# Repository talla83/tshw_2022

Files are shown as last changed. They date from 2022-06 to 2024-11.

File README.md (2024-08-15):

# tshw_2022
# PCB for Tom Simple CNC Handwheel (Mesa SmartSerial)

# Neue Dokumentation 2024 !!!
# https://www.patreon.com/posts/tom-simple-2024-110112296

- 16 Inputs / 16 Outputs / 2 Analog Inputs / 1 Encoder Input
- Interface: RS422
- Protocol: Mesa SmartSerial

The Frame: (3D Printing)
https://www.thingiverse.com/thing:3684937

This is an image

Achtung:
Die Pulldownwiderstände R7,R8,R9,R10,R11,R12,R13,R14,R15,R16,R17,R18,R19,R20,R21,R22 
können einen Wert zwischen 300 ohm bis 10 kOhm haben.

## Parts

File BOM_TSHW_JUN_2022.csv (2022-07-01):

ID | Name | Designator | Footprint | Quantity | Manufacturer Part | Manufacturer | Supplier | Supplier Part | Price
1 | 1K | R2,R1 | R1206 | 2 |  |  | LCSC | C510121 | 0.043
2 | 1K | R7,R8,R9,R10,R11,R12,R13,R14,R15,R16,R17,R18,R19,R20,R21,R22 | R1206 | 16 | 1K - 10K |  | LCSC | C510121 | 0.004
3 | 4,7K | R23,R25 | R1206 | 2 |  |  | LCSC | C510121 | 0.043
4 | 100nF | C10,C11,C1,C2,C3,C4,C5,C6,C7,C12,C13,C14,C15 | C1206 | 13 | FN21X104K500PXG | Prosperity Dielectrics | LCSC | C235732 | 0.007
5 | 74HC14D,653 | U2 | SOIC-14_L8.7-W3.9-P1.27-LS6.0-BL | 1 | 74HC14D,653 | Nexperia | LCSC | C5605 | 0.224
6 | 4.7K | R3,R4,R5,R6 | R1206 | 4 | RS-05K472JT | FH | LCSC | C115310 | 0.001
7 | HDR-M-2.54_1x4 | J9 | HDR-M-2.54_1X4 | 1 |  |  | LCSC | C124378 | 0.045
8 | HDR-M-2.54_1x2 | J8,J7 | HDR-M-2.54_1X2 | 2 |  |  | LCSC | C124375 | 0.027
9 | HDR-M-2.54_1x5 | ICSP1 | HDR-M-2.54_1X5 | 1 |  |  | LCSC | C358687 | 0.026
10 | HDR-M-2.54_1x6 | J1,J2 | HDR-M-2.54_1X6 | 2 |  |  | LCSC | C190819 | 0.037
11 | AMS1117-3.3 | L1 | SOT-223-3_L6.5-W3.4-P2.30-LS7.0-BR | 1 | AMS1117-3.3 | AMS | LCSC | C6186 | 0.14
12 | 10MHz | OSC1 | OSC-SMD_CSTCC_G_A | 1 | CSTCC10M0G53-R0 | MuRata | LCSC | C63590 | 0.262
13 | 15-21/G6C-AN1P2/2T | E1 | LED0805-RD_RED | 1 | 17-21UGC/TR8 | Everlight Elec | LCSC | C264418 | 0.053
14 | MAX3491ESD+T | U1 | SOP-14_L8.6-W3.9-P1.27-LS6.0-BL | 1 | MAX3491ESD+T | MAXIM | LCSC | C61053 | 2.846
15 | 74HC597D,652 | U3,U4 | SO-16_L9.9-W3.9-P1.27-LS6.0-BL | 2 | 74HC597D,652 | Nexperia | LCSC | C547129 | 1.121
16 | 74HC595D,112 | U5,U6 | SO-16_L9.9-W3.9-P1.27-LS6.0-BL | 2 | 74HC595D,112 | Nexperia | LCSC | C547124 | 0.303
17 | DSPIC33EP32MC204-I/PT | IC1 | TQFP-44_L10.0-W10.0-P0.80-BL | 1 | DSPIC33EP32MC204-I/PT | MICROCHIP | LCSC | C141373 | 6.813
18 | 47uF | C8 | CAP-SMD_L3.5-W2.8-R-RD | 1 | 10TPE47MAZB | PANASONIC | LCSC | C147768 | 0.638
19 | 22uF | C9 | CAP-SMD_L7.3-W4.3-FD | 1 | 25TQC22MYFD | PANASONIC | LCSC | C129172 | 0.666
20 | HDR-M-2.54_1x8 | J3,J4,J5,J6 | HDR-M-2.54_1X8 | 4 |  |  | LCSC | C190820 | 0.042

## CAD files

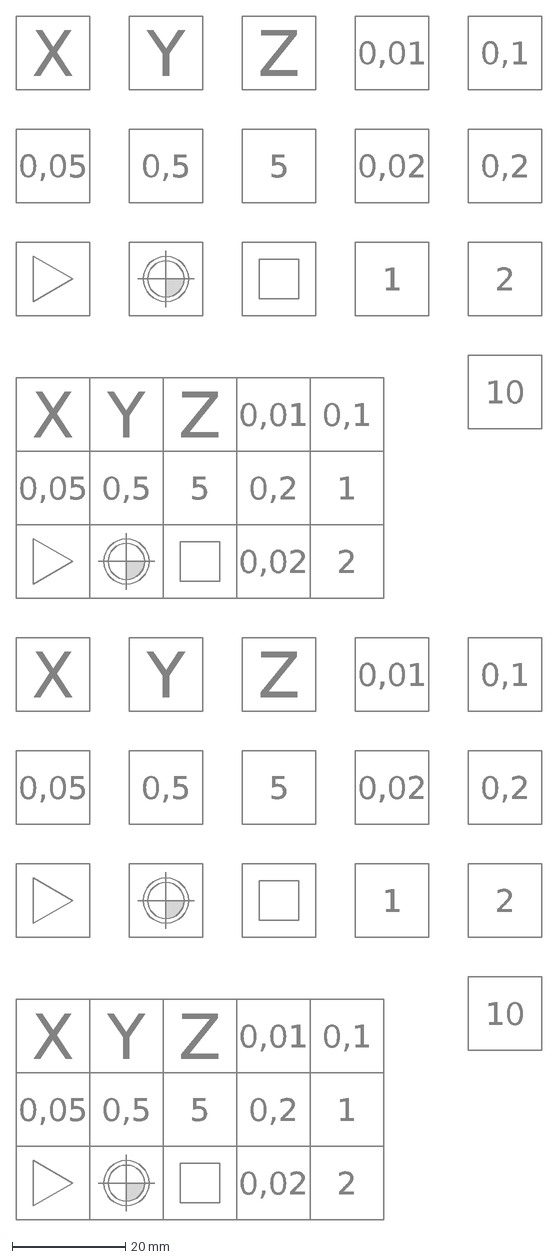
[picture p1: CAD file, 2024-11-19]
Handrad Druckdatei.dxf
X
Y
Z
0,05
0,5
5
0,01
0,1
1
0,02
0,2
2
10

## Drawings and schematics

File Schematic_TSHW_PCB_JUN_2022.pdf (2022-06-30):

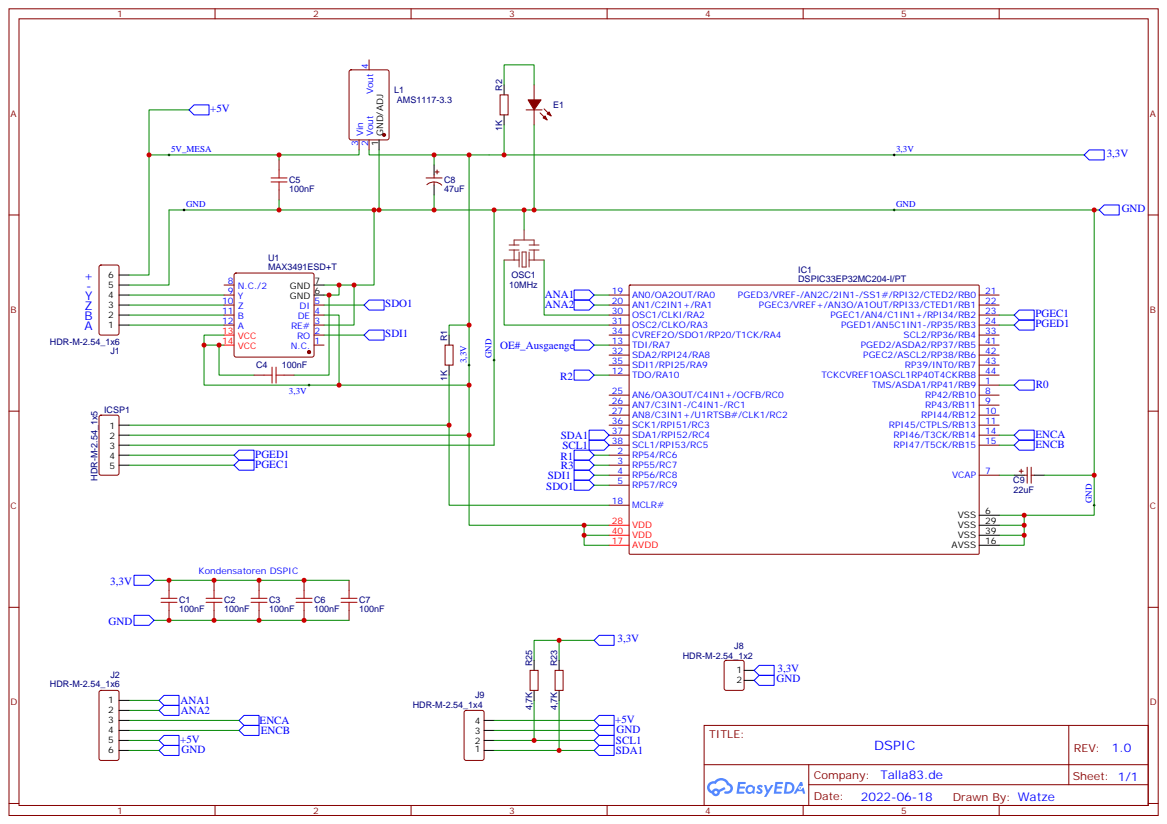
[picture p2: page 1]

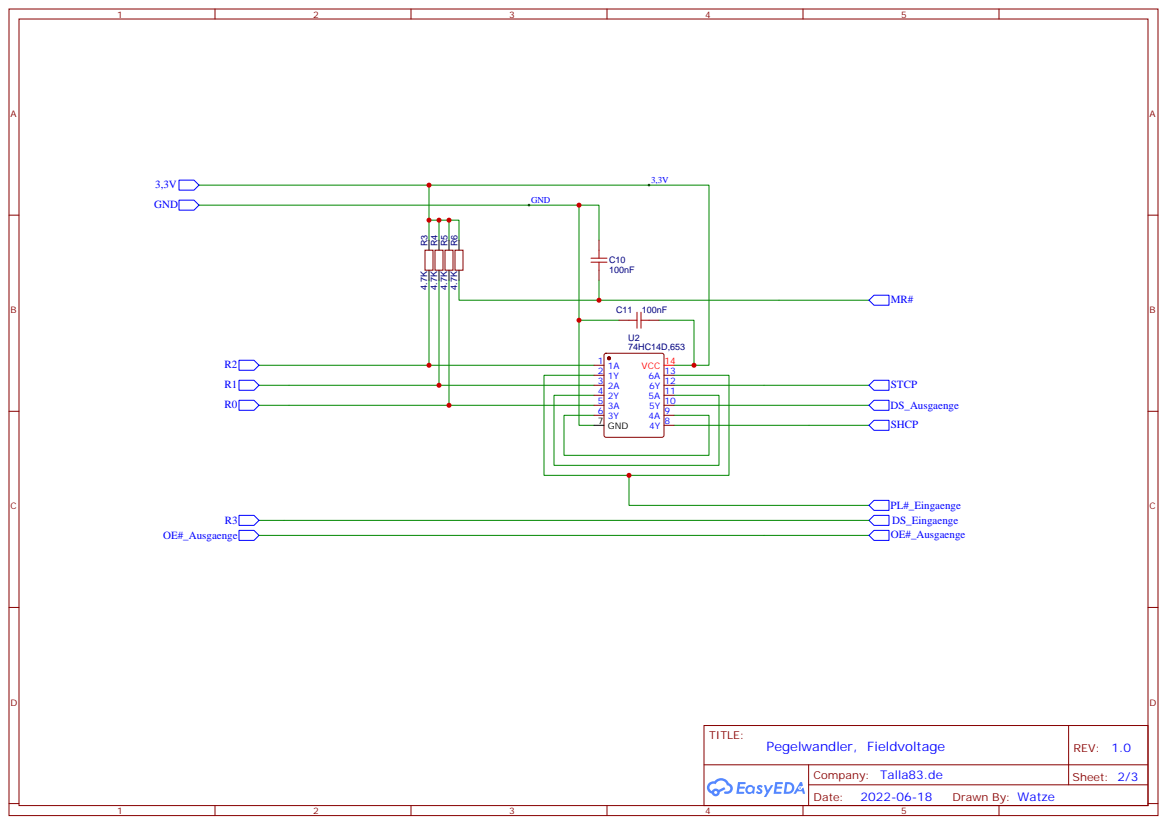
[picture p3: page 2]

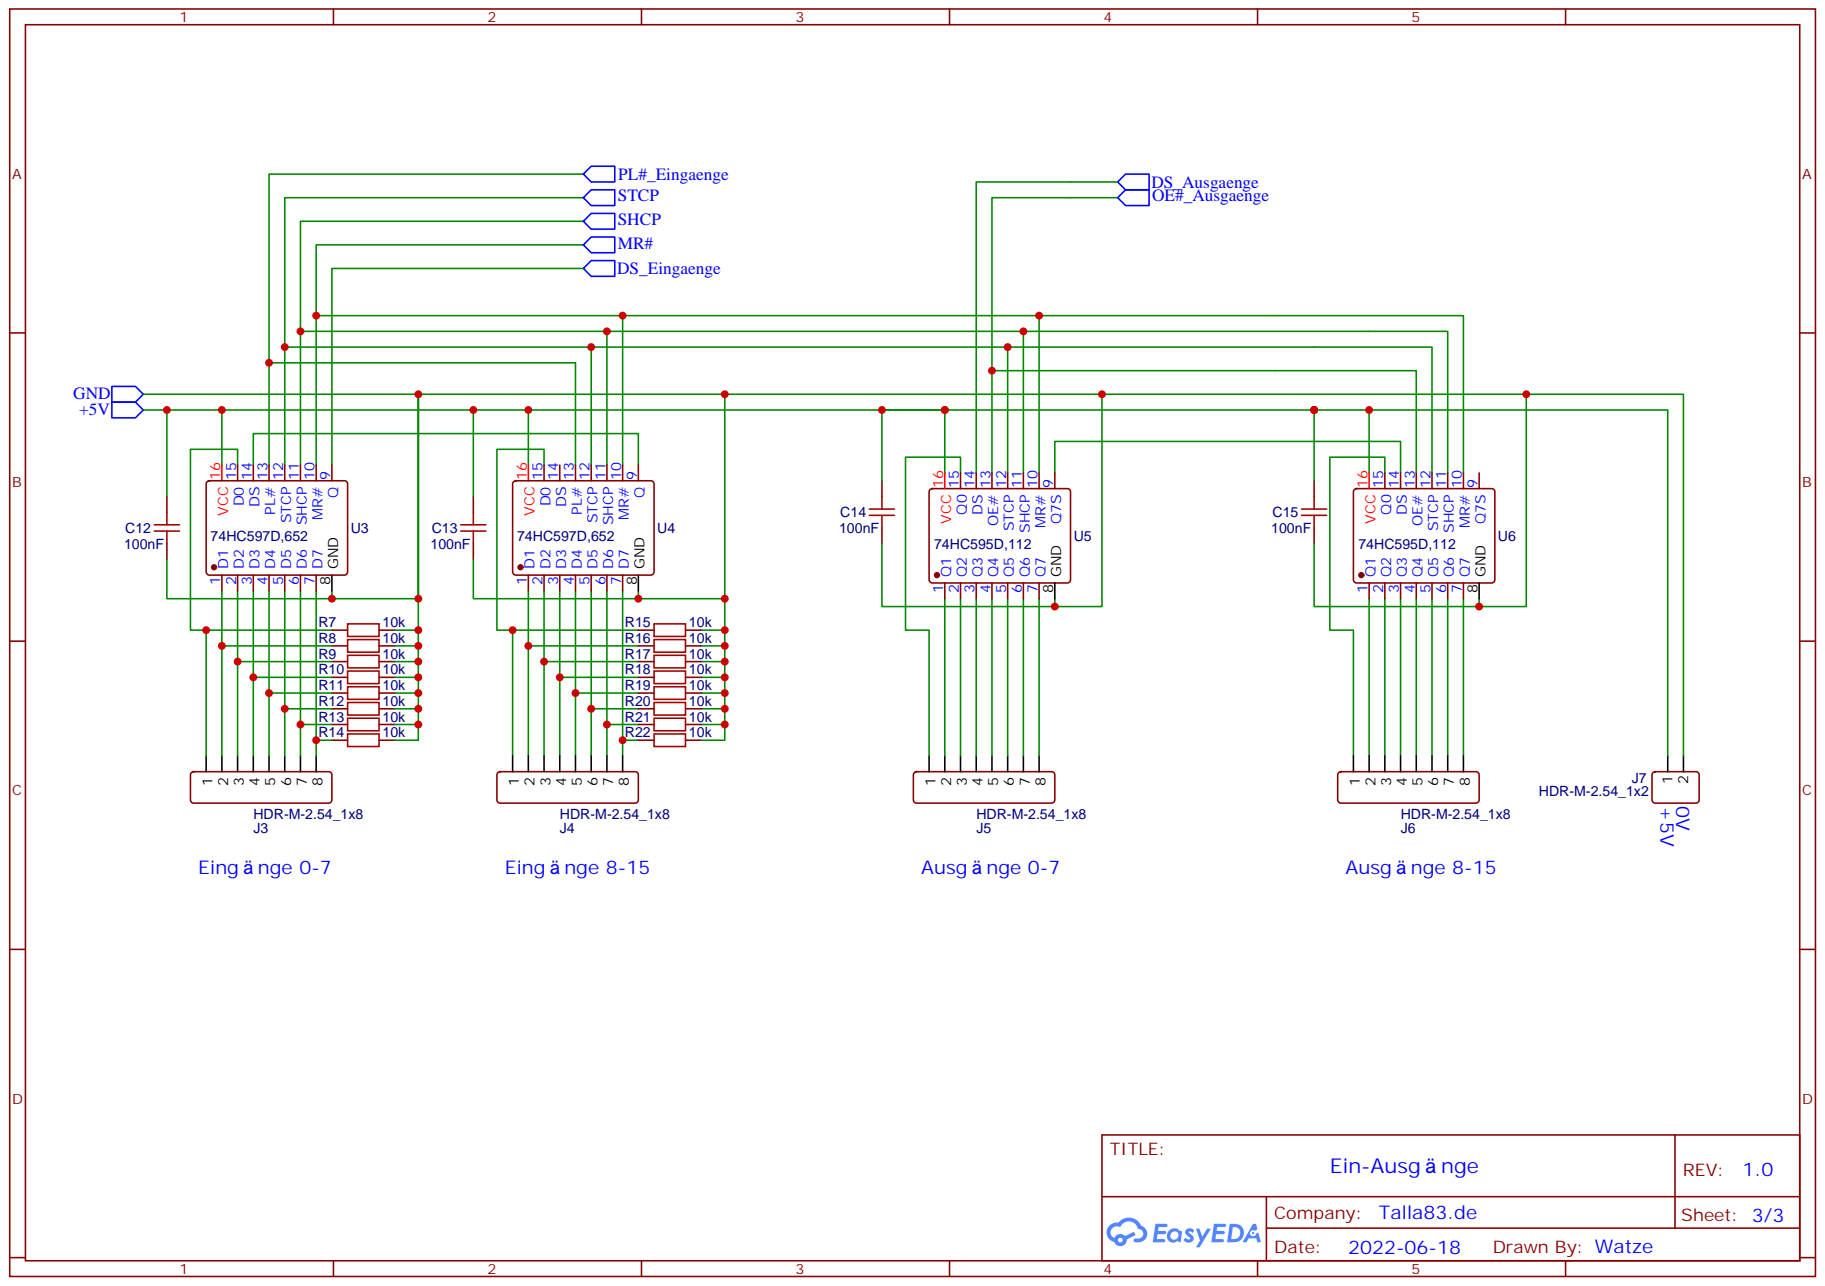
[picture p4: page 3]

9 MR# 10 SHCP 11 STCP 12 OE# 13 DS 14 Q0 15 VCC 16

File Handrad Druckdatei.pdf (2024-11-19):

X

Y

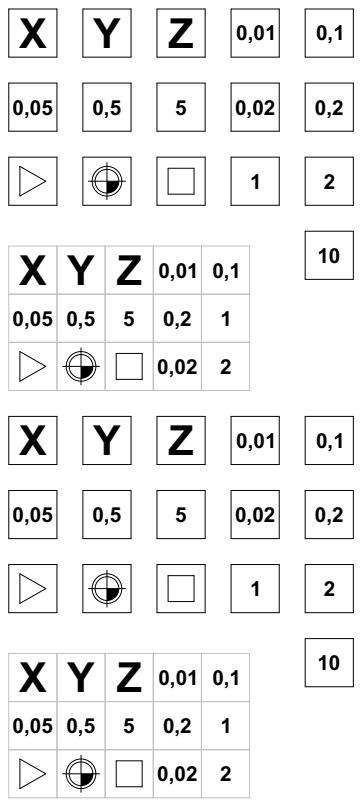
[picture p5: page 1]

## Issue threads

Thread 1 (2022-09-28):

Output Enable TSHW 2022

hhogendoorn, 2022-09-28:
Hallo Peter,
I think I have a problem with I think the latest HEX file TSHW_V4.0_june2022, the output enable pin from the PIC to the output buffer is always High. So the outputs are disabled. Is there a newer HEX file ?

talla83, 2022-09-28:
You have interpreted this correctly. The pin OE#_Ausgaenge is HIGH and becomes only LOW if a connection with LinuxCNC exists.

The current firmware is:
TSHW_V4.0_JUL_2022_beta_2.hex

Did you build the board yourself ?

hhogendoorn, 2022-09-28:
Hallo Peter,
I build the board myself. I think the connection between the tshw and the 7i76 I think is correct because in Halshow I see all swiches “moving” if pressed on the Tshw. ??
Thank you, Hans
Verstuurd vanaf mijn iPhone

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

talla83, 2022-09-28:
I just checked it again with a multimeter. The PIN goes LOW after the connection with LinuxCNC was established. The error must be somewhere else.

Maybe you have a solder bridge and this line is permanently connected to VDD.

hhogendoorn, 2022-09-28:
Ill check again, thank you very much!

Verstuurd vanaf mijn iPhone

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

hhogendoorn, 2022-09-29:
Hallo Peter, getting there slowly, it’s not the hardware but the Net naming in the Hal file.
Regards Hans

Verstuurd vanaf mijn iPhone

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
>>> Op 28 sep. 2022 om 17:05 heeft talla83 ***@***.***> het volgende geschreven:
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

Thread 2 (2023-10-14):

TsHW wil nicht starten

CNCGoos, 2023-10-14:
Hallo Peter,

Zu erst danke fur den schone Platine. ich habe geraad den erste gelot und Programiert. Programierunf lauft oke laut MPlab.

Jetzt habe ich den Platine am 7i76E angeschlossen und bekommen keine TsHW im HAlsshow.
Versucht zu hause den Platine am 5v DC verknopft und messe mit den scope keine OSc und eich keien Signalen am A B Y oder Z\.

eine 2e Geloted und zuerst nur den DSPIC mit den C's und 1K Res. und den Spanannungs versorgung un OSC. dan hatte ich etwas beim OSC am Scope gesehen. programiert. und weiterhin alles gelot. wieder kein erfolg.

hast du mit Solchem problemen mahl den fehler gefunden?

Danke im Voraus

talla83, 2023-10-27:
Diese Fehler habe ich noch nicht gehabt und sind mir auch nicht bekannt.
Hast du dich genau an die spezifischen Bauteile gehalten?
Vielleicht hast du auch Lötbrücken und fehlerhafte Lötstellen.
kannst du mal Detail Bilder Fotos machen von deinen gelöteten Platinen ?

talla83, 2023-10-28:
hier noch ein Video....Damit kannst du die wichtigen Stellen überprüfen.

https://www.youtube.com/watch?v=PMbjilklD_s

Am RS422 wirst du nichts messen so lange keine laufende Verbindung mit LinuxCNC besteht.

Gruß Peter

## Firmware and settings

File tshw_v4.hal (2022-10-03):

###################################################################
# TsHW Talla simple Hand Wheel  LinuxCNC Version 2.9
# TsHW V4 Platine 16xIN 16xOUT 2xANA 1xENC 
# 03.10.2022
###################################################################
# ilowpass und and2   
#
# Wenn diese schon in einer anderen HAL geladen bzw. verwendet werden,
# dann muss dies in der Struktur beachtet werden.
# Denn doppeltes laden von Komponenten ist nicht möglich.
# Es müssen die loadrt Befehle auskommentiert werden und
# die loadrt Befehle in den anderen HAL Dateien mit diesen Namen 
# ergänzt werden.
# addf kann hier bleiben :-)
# 
# Damit der Zero der Achsen geht müssen in der INI die MDI Commands 
# angelegt werden 
#
#	[HALUI]
#	MDI_COMMAND = G10 L20 P1 X0
#	MDI_COMMAND = G10 L20 P1 Y0
#	MDI_COMMAND = G10 L20 P1 Z0
#
#
#
# Mit setp shw.enc-smooth.gain  kann die Beschleunigung eingestellt werden.
# und mit setp shw.enc-smooth.scale die Übersetzung
#
###################################################################

####################
##      TsHW      ##
####################

loadrt ilowpass names=shw.enc-smooth
addf shw.enc-smooth servo-thread

setp shw.enc-smooth.scale 1
setp shw.enc-smooth.gain  0.025

setp axis.x.jog-vel-mode 1
setp axis.y.jog-vel-mode 1
setp axis.z.jog-vel-mode 1

loadrt and2 names=shw.ena-x,shw.ena-y,shw.ena-z,shw.zero-x,shw.zero-y,shw.zero-z

addf shw.ena-x servo-thread
addf shw.ena-y servo-thread
addf shw.ena-z servo-thread

addf shw.zero-x servo-thread
addf shw.zero-y servo-thread
addf shw.zero-z servo-thread

loadrt mux8 names=shw.step-choice
addf shw.step-choice servo-thread

net key-0001  => shw.step-choice.sel0
net key-001   => shw.step-choice.sel1
net key-01    => shw.step-choice.sel2

setp shw.step-choice.in1 0.001
setp shw.step-choice.in2 0.01
setp shw.step-choice.in4 0.1

net step-choice <= shw.step-choice.out
net step-choice => axis.x.jog-scale
net step-choice => axis.y.jog-scale
net step-choice => axis.z.jog-scale

net key-0001  <= hm2_7i76e.0.TsHW.0.1.input-06
net key-0001  => hm2_7i76e.0.TsHW.0.1.output-06
net key-001   <= hm2_7i76e.0.TsHW.0.1.input-05
net key-001   => hm2_7i76e.0.TsHW.0.1.output-05
net key-01    <= hm2_7i76e.0.TsHW.0.1.input-04
net key-01    => hm2_7i76e.0.TsHW.0.1.output-04

net key-x <= hm2_7i76e.0.TsHW.0.1.input-01
net key-x => hm2_7i76e.0.TsHW.0.1.output-01
net key-x => shw.ena-x.in0
net ena-x shw.ena-x.out => axis.x.jog-enable

net key-y <= hm2_7i76e.0.TsHW.0.1.input-02
net key-y => hm2_7i76e.0.TsHW.0.1.output-02
net key-y => shw.ena-y.in0
net ena-y shw.ena-y.out => axis.y.jog-enable

net key-z <= hm2_7i76e.0.TsHW.0.1.input-03
net key-z => hm2_7i76e.0.TsHW.0.1.output-03
net key-z => shw.ena-z.in0
net ena-z shw.ena-z.out => axis.z.jog-enable

net key-ena <= hm2_7i76e.0.TsHW.0.1.input-00
net key-ena => shw.ena-x.in1
net key-ena => shw.ena-y.in1
net key-ena => shw.ena-z.in1
net key-ena => halui.mode.manual
net key-ena => axisui.notifications-clear
net key-ena => hm2_7i76e.0.TsHW.0.1.output-00

net enc-00 shw.enc-smooth.in <= hm2_7i76e.0.TsHW.0.1.encoder-0.count
net enc-01 <= shw.enc-smooth.out
net enc-01 => axis.x.jog-counts
net enc-01 => axis.y.jog-counts
net enc-01 => axis.z.jog-counts

net key-03 <= hm2_7i76e.0.TsHW.0.1.input-07 
net key-03 => halui.program.run
net key-03 => halui.mode.auto
net led-03 <= halui.program.is-running
net led-03 => hm2_7i76e.0.TsHW.0.1.output-07

net key-04 <= hm2_7i76e.0.TsHW.0.1.input-08 
net key-04 => hm2_7i76e.0.TsHW.0.1.output-08
net key-04 => shw.zero-x.in1
net key-04 => shw.zero-y.in1
net key-04 => shw.zero-z.in1
net key-04 => halui.mode.mdi

net key-z => shw.zero-z.in0
net key-x => shw.zero-x.in0
net key-y => shw.zero-y.in0

net zero-x shw.zero-x.out => halui.mdi-command-00
net zero-y shw.zero-y.out => halui.mdi-command-01
net zero-z shw.zero-z.out => halui.mdi-command-02

net key-09 <= hm2_7i76e.0.TsHW.0.1.input-09 
net key-09 => halui.program.stop
net led-09 <= halui.program.is-idle
net led-09 => hm2_7i76e.0.TsHW.0.1.output-09

net key-10 <= hm2_7i76e.0.TsHW.0.1.input-10

###################################################################

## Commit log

2022-06-30 Add files via upload
    Pulldown Widerstände geändert.
    Damit reduziert sich der Stromverbrauch.
    Grundlegend können die Werte der 16 Widerstände R7 bis R22 zwischen 300 Ohm und 10Kohm liegen.
    [BOM_TSHW_JUN_2022.csv]
2022-10-03 Add files via upload
    HAL EXAMPLE
    TOM SIMPLE HANDWHEEL
    [tshw_v4.hal]
2024-11-19 Labels für die Taster.
    Danke an Julian der diese zur Verfügung gestellt hat.
    [Handrad Druckdatei.dxf]
2026-01-30 Create TSHW_V4.2_JAN_2026.hex
    Bei der TSHW-Platine wurde ein Bug festgestellt. Im Falle einer fehlenden oder unterbrochenen Kommunikation wurden die Ausgänge nicht in einen definierten sicheren Zustand versetzt, sondern teilweise unkontrolliert geschaltet. Dieses Verhalten konnte zu unerwarteten Schaltzuständen der Ausgänge führen. Diese Firmware behebt dieses Phänomen und stellt sicher, dass die Ausgänge bei Kommunikationsverlust in einen definierten Zustand wechseln.
2026-03-27 Add files via upload
    Sometimes a connection is not established.
    UART timing was adjusted to fix the problem.
